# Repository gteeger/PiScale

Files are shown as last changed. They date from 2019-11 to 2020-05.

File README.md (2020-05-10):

# PiScale

### Updates:
May 10th 2020

1) Proper error codes get returned when doing I2C programming of mpu6050
2) Safety checks on the arguments passed to ioctl function in kernel space from user space.

April 7th 2020

1) I switched to [these load sensors from Sparkfun](https://www.sparkfun.com/products/10245).
2) PCB designed in KiCAD to integrate various components. See hardware folder for schematic, layout, BOM, and gerbers.
3) The PCB is compatible with either Arduino or Raspberry Pi. There are through holes in the PCB to mount an Arduino Nano.
4) There are numerous taps on the PCB allowing external connection to a Raspberry Pi.
5) Jumpers are used to disconnect the Arduino and Raspberry Pi 3V3 and 5V power supplies.
6) On board buttons can be used to trigger interrupts.
7) There is a circuit to properly combine 4 half-bridge load sensors based on the [combinator board](https://www.sparkfun.com/products/13878) from Sparkfun. The correct connections for the 4 load sensors are written in silk screen on the PCB (UL: upper left, UR: upper right, LL: lower left, LR: lower right ).
8) It is also possible to attach a [full bridge load sensor](https://www.sparkfun.com/products/13329) to the pins on the PCB marked E+, E-. A+, A-, B+, B-.
9) There is room for an MPU-6050 to be mounted on the PCB, and pins to connect and LCD. Both the MPU and the LCD pins are connected to I2C SDA and SCL lines.
10) You can connect an external power supply to the PCB (Like a 9V battery) that is connected to the Vin pin of the Arduino.
11) Jumpers are used to connect to either the A or B channel of the HX711 (see the HX711 datasheet for more information on A and B channels).
12) A jumper is used to connect the HX711 to either a 5V or 3V3 power supply.
13) Arduino code is still in progress but Raspberry Pi code still works fine.
14) The MPU6050 ISR on the Raspberry Pi is now broken up into top and bottom halves.

 
 
 PCB Front
 PCB Back
 
Jan 26th 2020
1) User-space program is now written in C++ with an interface to a Scale class.
2) Pressing ctrl+c while program is running issues a signal to abort the program and notifies kernel space to take appropriate action (unlock mutexes, notify waiting tasks).
3) Tare function included as part of Scale class.
4) IOCTL is used to communicate between user and kernel space to:
  a) Send abort signal.
  b) Change timeout duration.
  
### Raspberry Pi Prerequisites
1) You have to enable the avia-hx711 driver using ```menuconfig```  and rebuild the kernel. ([Raspberry Pi tutorial](https://www.raspberrypi.org/documentation/linux/kernel/building.md)) As a side note, do not activate the existing invensense mpu-6050 kernel driver. The mpu-6050 is directly programmed by my driver, specifically to activate motion sensing. 
2) You have to add the custom device tree overlay in the device tree folder to your personal device. I built the .dtbo using the ```dtc``` command and made sure it was added to the device tree.([Raspberry Pi tutorial](https://www.raspberrypi.org/documentation/configuration/device-tree.md))
3) Make the included script executible using ```chmod u+x piscale_script.sh```



Hardware Legend:
1) 30 kg Load Sensor
2) [HX711](https://www.sparkfun.com/products/13879) : this is an IC which is a combination of an analog to digital converter and programmable gain amplifier. It uses a bit-banging protocol, so its clock and data lines must be connected to GPIO pins. 
3) [MPU-6050](https://www.sparkfun.com/products/11028) : Accelerometer/Gyroscope. Used as a motion detector.
4) [Raspberry Pi 3 A+](https://www.raspberrypi.org/products/raspberry-pi-3-model-a-plus/4)

The pin connections are:

| Raspberry Pi | HX711 |
|---|---|
| BCM pin 23 | CLK |
| BCM pin 24 | DAT |
| 3V3 | VCC&VDD |

| Raspberry Pi | MPU6050 |
|---|---|
| I2C1 SDA | SDA |
| I2C1 SCL | SCL |
| 3v3 | VCC |
| BCM pin 17 | INT |

Type ```$ ./piscale_script.sh``` to build everything, insert modules into kernel, and run the application.

### Description

By design, the whole process is handled is very efficient. Despite the userspace program starting 2 threads, each with a while(1) loop, the system consumes a negligible amount of computing power. Two separate kernel modules are built and added into the kernel. The first module activates highly sensitive motion interrupts in the mpu 6050. Whenever a slight amount of motion is detected, the INT pin on the mpu 6050 goes high momentarily.

The second kernel module **handles** the motion interrupt by registering an interrupt and attaching a handler function. The module uses ```wake_up_interruptible``` and ```wait_event_interruptible``` to sleep while waiting for a motion interrupt. When an interrupt is received, the system is signalled to be active for 40 seconds (time can be changed in header file). The timer restarts everytime a motion interrupt is received and the system remains active for another 60 seconds. During the active period, the user space application is woken-up and a producer-consumer situation safely takes place without any race conditions. The consumer thread sleeps when there is no more data to consume.

## Flowchart of system



Feel free to contact me at gabe.teeger@gmail.com if you have any questions.

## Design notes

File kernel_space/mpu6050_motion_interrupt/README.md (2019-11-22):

# Motion Interrupt on Raspberry Pi 3 A+ with an MPU6050 IMU 

*Before building, specify in the driver which i2c adapter you want to connect to (ex: i2c-1)*

This is a very basic driver to enable motion interrupts on an MPU 6050.

After you insert this driver into the kernel, you're mpu6050's INT pin will go high then low when motion is detected.

There are no loops, the driver simply configures the mpu6050 over I2C.

You can use any linux board but I used a Raspberry Pi with the mpu connected to i2c-1 (verified with i2c-tools). 

Commands:
```
$ make
$ sudo insmod mpu6050.ko
...(mpu is detecting motion)..
$ sudo rmmod mpu6050.ko
...(mpu goes to sleep)...
```

Output from oscilloscope hooked up to interrupt pin of MPU6050 when motion is detected:


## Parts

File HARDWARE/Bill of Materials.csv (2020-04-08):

ref | value | footprint
BT1 | BATTERY | 0.1 inch pins
C1 | 10uF | SM0805
C2 | 0.1uF | SM0805
C3 | 0.1uF | SM0805
C4 | 0.1uF | SM0805
C5 | 0.1uF | SM0805
C6 | 10uF | SM0805
C7 | 0.1uF | SM0805
C8 | 0.1uF | SM0805
D1 | LED | SM0805
JP1 | JUMPER3 | 0.1 inch pins
JP2 | JUMPER3 | 0.1 inch pins
JP3 | JUMPER3 | 0.1 inch pins
JP4 | JUMPER | 0.1 inch pins
JP5 | JUMPER | 0.1 inch pins
JP6 | JUMPER | 0.1 inch pins
L1 | 3.3uH | SM0805
P1 | BUTT1 | 0.1 inch pins
P2 | DAT | 0.1 inch pins
P3 | CLK | 0.1 inch pins
P4 | INT | 0.1 inch pins
P5 | VCC | 0.1 inch pins
P6 | GND | 0.1 inch pins
P7 | 3V3 | 0.1 inch pins
P8 | SDA | 0.1 inch pins
P9 | 5V | 0.1 inch pins
P10 | SCL | 0.1 inch pins
Q1 | PNP | SOT-23
R1 | 20K | SM0805
R2 | 8.2K | SM0805
R3 | 100R | SM0805
R4 | 100R | SM0805
R5 | 100R | SM0805
R6 | 10K | SM0805
R7 | 100R | SM0805
R8 | 220R | SM0805
R9 | 10K | SM0805
R10 | 10K | SM0805
R11 | 0R | SM0805
SW1 | SW_PUSH | https://www.digikey.ca/product-detail/en/omron-electronics-inc-emc-div/B3F-1000/SW400-ND/33150?productid=33150
SW2 | SW_PUSH | https://www.digikey.ca/product-detail/en/omron-electronics-inc-emc-div/B3F-1000/SW400-ND/33150?productid=33150
U1 | UL | 0.1 inch pins
U2 | LOAD_SENSOR_JMP | 0.1 inch pins
U3 | UR | 0.1 inch pins
U4 | LL | 0.1 inch pins
U5 | LR | 0.1 inch pins
U6 | HX711 | See datasheet
U7 | ARDUINO2 | https://www.amazon.ca/Arduino-ELEGOO-ATmega328P-Compatible-Without/dp/B071NMD14Y
U8 | MPU6050 | https://www.amazon.ca/Gikfun-MPU-6050-Accelerometer-Gyroscope-EK1091x3C/dp/B07JPK26X2?s=electronics
U9 | LCD | Any LCD with I2C connection

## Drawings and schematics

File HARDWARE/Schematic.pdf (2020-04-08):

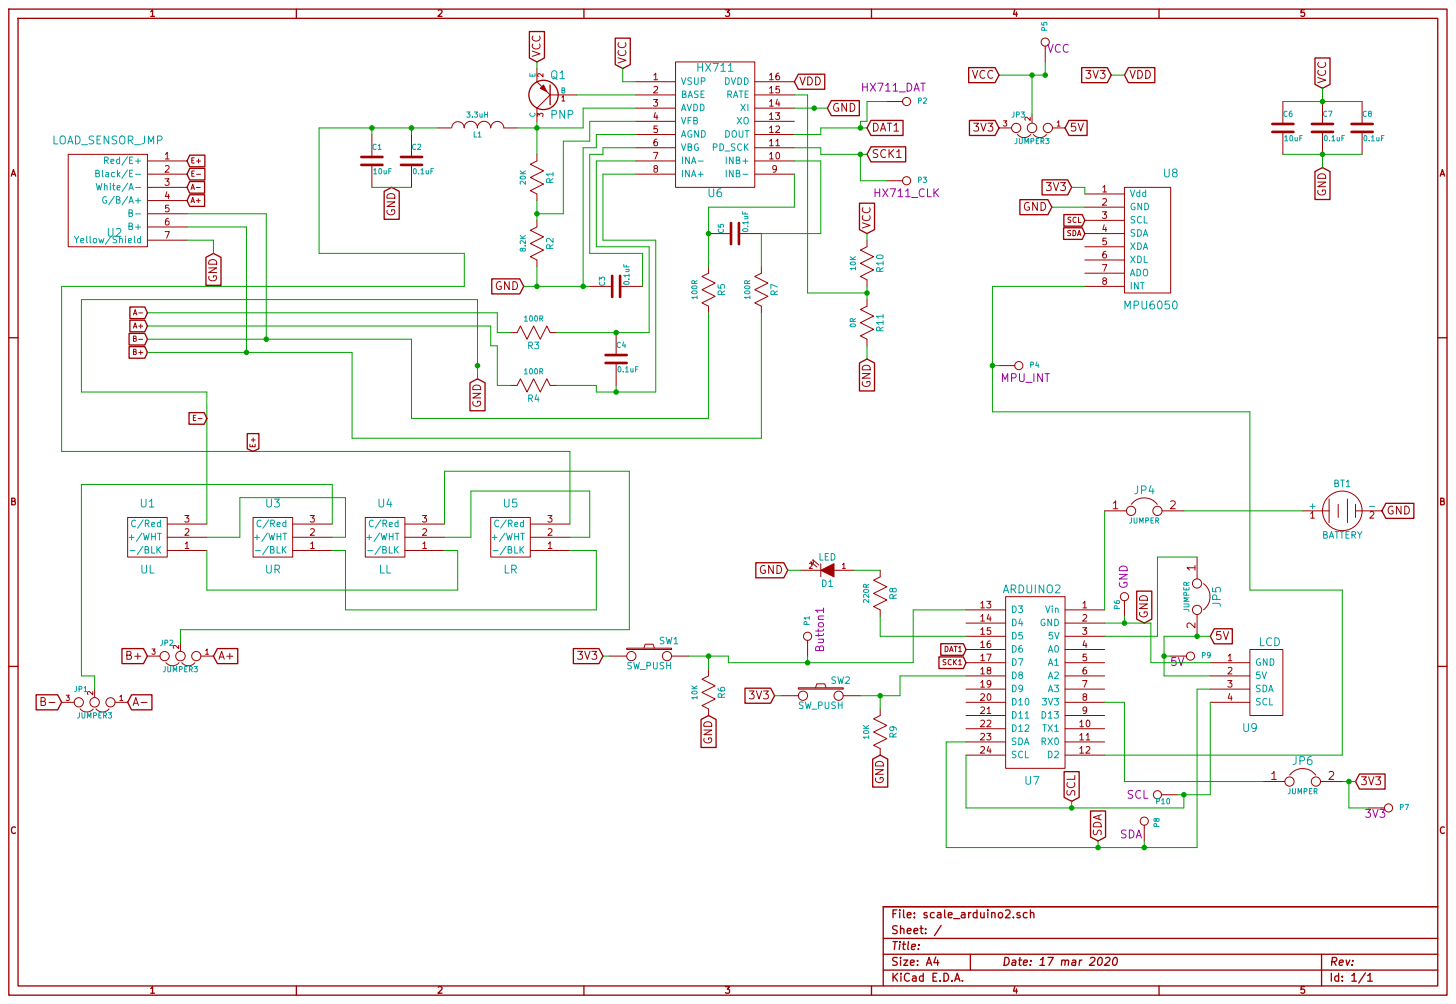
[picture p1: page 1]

Id: 1/1 Title: File: scale_arduino2.sch
Sheet: /

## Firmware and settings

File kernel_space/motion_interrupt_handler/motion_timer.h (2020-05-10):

#ifndef MOTION_TIMER_H
#define MOTION_TIMER_H

#include <linux/ioctl.h>
typedef uint8_t __u8;
//its highly likely that these will be attempted to be redefined
#ifndef TRUE
#define TRUE 1 //redefined in header
#endif
#ifndef FALSE
#define FALSE 0 //redefined
#endif
#ifndef RUNNING
#define RUNNING 1
#endif
#ifndef OFF
#define OFF 0 //redefined
#endif
#ifndef ON
#define ON 1 //redefined
#endif

#define HI (1)
#define LO (0)

#define GPIO_INT_PIN (17)  //BCM 17

#define DEFAULT_TIMEOUT_MS (1000) //1 second
#define DEFAULT_TIMEOUT_JIFFIES msecs_to_jiffies(DEFAULT_TIMEOUT_MS)
#define MAJOR_NUM (117)

#define MEASURING (1)

#define IOCTL_MAGIC 'k'

#define TIMEOUT_CHANGE _IOW(IOCTL_MAGIC, 1, __u8)
#define ABORT_SIG _IO(IOCTL_MAGIC, 2)

#define TIMEOUT_LIMIT_MS (2000000) // ~30 mins
#define TIMEOUT_MIN_MS (500) //0.5 seconds
 

#endif

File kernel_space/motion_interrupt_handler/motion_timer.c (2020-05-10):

#include <linux/module.h>
#include <linux/init.h>
#include <linux/interrupt.h>
#include <linux/timer.h>
#include <linux/kernel.h>
#include <linux/gpio.h>
#include <linux/delay.h>
#include <linux/jiffies.h>
#include <linux/uaccess.h>
#include <linux/wait.h>

#include "motion_timer.h"

#define DEBUG 1

static struct timer_list timer;
static void timeout(struct timer_list *t);
static irqreturn_t irq_handler(unsigned int irq, void *dev_id,
			       struct pt_regs *regs);
int irq_number;
char dev_status;
volatile bool change;
volatile bool abort_sig;
static DECLARE_WAIT_QUEUE_HEAD(intrpt_waitqueue);
static int custom_timeout;

void bottom_half_tasklet(unsigned long x);
DECLARE_TASKLET(bottom_half, bottom_half_tasklet, 0);

static void timeout(struct timer_list *t)
{

#if DEBUG
    u64 safe_jiffies = get_jiffies_64();
    printk(KERN_ALERT "TIMEOUT!\n");
    printk(KERN_ALERT "JIFFIES: %lld\n", safe_jiffies);
#endif
    dev_status = OFF;
    change = TRUE;
    wake_up_interruptible(&intrpt_waitqueue);

}

static irqreturn_t irq_handler(unsigned int irq, void *dev_id,
			       struct pt_regs *regs)
{
    tasklet_schedule(&bottom_half);
    return IRQ_HANDLED;
}


void bottom_half_tasklet(unsigned long x)
{

    u64 safe_jiffies = get_jiffies_64();
#if DEBUG
    printk(KERN_ALERT "Inside the %s function\n", __FUNCTION__);
#endif
    dev_status = MEASURING;
    mod_timer(&timer, safe_jiffies + custom_timeout);
    change = TRUE;
    wake_up_interruptible(&intrpt_waitqueue);

}

static int dev_open(struct inode *inode, struct file *filp)
{

#if DEBUG
    printk(KERN_ALERT "Inside the %s function\n", __FUNCTION__);
#endif

    return 0;
}


static ssize_t dev_read(struct file *filp, char __user * buf,
			size_t count, loff_t * f_pos)
{
#if DEBUG
    printk(KERN_ALERT "Inside the %s function\n", __FUNCTION__);
#endif
    wait_event_interruptible(intrpt_waitqueue, change == TRUE
			     || abort_sig == TRUE);

#if DEBUG
    printk(KERN_ALERT "dev status = %d\n", dev_status);
#endif

    if (copy_to_user(buf, &dev_status, count)) {
#if DEBUG
	printk(KERN_ALERT "Copy to user space failed");
#endif
	return -EFAULT;
    }
    change = FALSE;
    abort_sig = FALSE;
    return 0;
}

static long scale_ioctl(struct file *filp, unsigned int cmd,
			unsigned long arg)
{
    unsigned long t_out;
#if DEBUG
    printk(KERN_ALERT "Inside the %s function\n", __FUNCTION__);
    printk(KERN_ALERT "cmd =  %d \n", cmd);
#endif
    switch (cmd) {
    case ABORT_SIG:
	printk(KERN_ALERT "Abort Signal received\n");
	abort_sig = TRUE;
	wake_up_interruptible(&intrpt_waitqueue);
	break;

    case TIMEOUT_CHANGE:
	/*
	 * We have to check whether arg is a valid input
	 * If the user enters a negative number, then
	 * t_out will be a large positve number.
	 */
	if (arg > TIMEOUT_LIMIT_MS) {
	    arg = TIMEOUT_LIMIT_MS;
	}
	if (arg < TIMEOUT_MIN_MS) {
	    arg = TIMEOUT_MIN_MS;
	}
	t_out = msecs_to_jiffies(arg);
	printk(KERN_ALERT "timeout changed to %lu\n", t_out);
	custom_timeout = t_out;
	break;

    default:

	break;

    }


    return 0;
}


static int dev_release(struct inode *inode, struct file *filp)
{
#if DEBUG
    printk(KERN_ALERT "Inside the %s function\n", __FUNCTION__);
#endif
    return 0;
}



static const struct file_operations dev_fops = {
    .owner = THIS_MODULE,
    .read = dev_read,
    .open = dev_open,
    .unlocked_ioctl = scale_ioctl,
    .release = dev_release,
};


static int __init motion_timer_init(void)
{

    int status;
    int errno1, errno2;
    unsigned long IRQflags = IRQF_TRIGGER_RISING;
    custom_timeout = DEFAULT_TIMEOUT_JIFFIES;
    change = FALSE;
    abort_sig = FALSE;
#if DEBUG
    printk(KERN_ALERT "Inside the %s function\n", __FUNCTION__);
#endif
    timer_setup(&timer, timeout, 0);
    errno1 = gpio_request(GPIO_INT_PIN, "irq_gpio_pin");
    mdelay(50);
    errno2 = gpio_direction_input(GPIO_INT_PIN);
    if (errno1 < 0 || errno2 < 0) {
#if DEBUG
	printk(KERN_ALERT "cannot map gpio with errno1 %d\n", errno1);
	printk(KERN_ALERT "cannot map gpio with errno2 %d\n", errno2);
#endif
	return -1;
    }
    irq_number = gpio_to_irq(GPIO_INT_PIN);
    if (irq_number < 0) {
	printk(KERN_ALERT "Unable to map IRQ");
	return irq_number;
    }
#if DEBUG
    printk(KERN_ALERT "gpio mapped to irq %d", irq_number);
#endif
    status = request_irq(irq_number,
			 (irq_handler_t) irq_handler,
			 IRQflags, "mpu_int_handler", NULL);
    if (status < 0) {
	printk(KERN_ALERT "Unable to request IRQ");
	return status;
    }
    status = register_chrdev(MAJOR_NUM, "motion_timer_dev", &dev_fops);

    dev_status = OFF;

    return status;

}

static void __exit motion_timer_exit(void)
{
#if DEBUG
    printk(KERN_ALERT "Inside the %s function\n", __FUNCTION__);
#endif
    del_timer(&timer);
    free_irq(irq_number, NULL);
    gpio_free(GPIO_INT_PIN);
    unregister_chrdev(MAJOR_NUM, "motion_timer_dev");
}


module_init(motion_timer_init);
module_exit(motion_timer_exit);

MODULE_AUTHOR("Gabe Teeger");
MODULE_DESCRIPTION("start timer when motion interrupt is received");
MODULE_LICENSE("GPL");

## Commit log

2020-02-19 added STL vector class and some other c++11 features
2020-04-08 Hardware files added, code files organized
    [Bill of Materials.csv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]
2020-05-10 return proper error codes in mpu programmer, safety check on ioctl arg
    [motion_timer.c, motion_timer.h, mpu6050.c]
